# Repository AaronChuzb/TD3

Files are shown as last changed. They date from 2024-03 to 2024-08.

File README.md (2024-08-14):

# TD3-TouchDisplay3.0

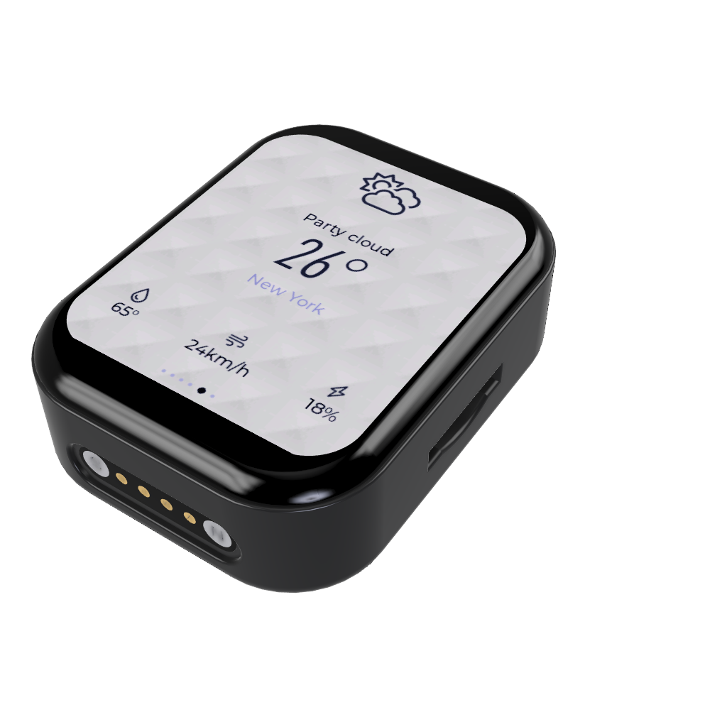
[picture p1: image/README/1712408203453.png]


# 介绍视频



[B站早期视频](https://player.bilibili.com/player.html?isOutside=true&aid=1853047000&bvid=BV1cp421R78N&cid=1508688648&p=1)

# 复刻注意事项

- 板子厚度选择1.2mm
- 阻抗匹配无要求
- 晶振要买无源的啊（血的教训）

## 锂电池

锂电池使用 `402530`的大小，容量 `300mAh`，目前同体积没找到更好的替代品，体积超过这个规格不适用我的外壳可能放不进去。

购买链接：[【淘宝】限时满20减2 https://m.tb.cn/h.gPwur8v7pjAurAq?tk=iaC63e7ytO5 MF6563 「3.7V聚合物锂电池对讲机故事机行车记录仪音箱通用大容量内置电池」](https://m.tb.cn/h.gPwur8v7pjAurAq?tk=iaC63e7ytO5)

记得叫商家加 `SH1.0`的头子,加头子是免费的，接口方向参考下图，方向跟板子上的母座方向是适配的，当然可以选择不接，同时也不焊接板子上的母座，直接飞线到板子上，但是SH1.0的座子引脚间距还是比较小的。

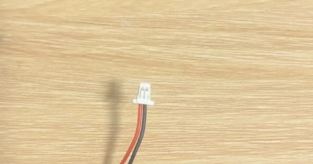
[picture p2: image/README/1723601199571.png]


## 磁吸接口

磁吸接口购买链接尽量使用bom表中的购买地址，3d模型我已经建好了，接口线序我也测过了，直接在那家店买线就ok，未来可能会画一个底座兼容TYPE-C插头。

购买链接：[【淘宝】https://m.tb.cn/h.glr8JNFoAGLjC2Y?tk=W5ul3eFrBDn CZ3460 「pogo pin磁吸式连接器公母带螺丝孔安装 弹簧顶针USB充电导电PIN」
点击链接直接打开 或者 淘宝搜索直接打开](https://m.tb.cn/h.glr8JNFoAGLjC2Y?tk=W5ul3eFrBDn)

购买下面 `4pin`的线，座子 `选弯头3.0mm的但是实际不是要3mm的`，要找客服说要2.54mm的 他们没挂链接，所以只能这样拍,记得一定要联系客服联系客服！！

## 无线充电

目前这块芯片在淘宝上好像只有一家代理商，并且配套的线圈在他们那里也能买到，这块芯片的外围阻容对材质是有要求的，`请先看数据手册的典型电路，再去购买对应的阻容，这一点在bom表中并没有体现出来`。数据手册那些问商家要就好了，项目的docs文件夹里边也有。

购买链接：[【淘宝】https://m.tb.cn/h.glhmi1BjbDgyDQN?tk=bRlC3eFFOLT MF7997 「原装现货代理伏达无线充电接收芯片NU1680/NU1680C，符合Qi标准」
点击链接直接打开 或者 淘宝搜索直接打开](https://m.tb.cn/h.glhmi1BjbDgyDQN?tk=bRlC3eFFOLT)

线圈选他们店里的NU1680配套线圈记得选 `方的`那块

## 屏幕BTB座

型号：`OK-14GF024-04`母座

这座子超过5毛就不要买了，有点难焊，建议淘宝打个钢网配合铁板烧或者风枪吹脚，尽量多买一点。

## 2.4G陶瓷天线

6块钱20片要什么自行车？商家估计还会主动联系帮做匹配电路，其实也不用板子我实测TX可以到18dbm，某C3板子开到15都不行。板子上预留了Π型电路，牛逼的大佬可以自己做天线的阻抗匹配。

购买链接：[【淘宝】https://m.tb.cn/h.glhqlfbUDg5LPQ1?tk=XRp63eFBeyH MF1643 「原装贴片天线3216蓝牙天线CW324WIFI2.4G 2.5G 4G 5G陶瓷1206天线」
点击链接直接打开 或者 淘宝搜索直接打开](https://m.tb.cn/h.glhqlfbUDg5LPQ1?tk=XRp63eFBeyH)

## AXP173电源管理芯片

这片子确实不太好买，定制电压的版本太多，而且停产挺久了，用这个方案主要是我手里还有十几块没用完。
可以在淘宝上购买一两片样片回来测试，`只需要DCDC1输出是3.3V`就OK。

买到合适的可以提一个issure，或者直接提一个pr，更新到这个表当中

| DCDC1输出 | 价格 | 购买链接 |
| --- | ---- | --- |
| | | |
| | | |

## 蜂鸣器

淘宝搜`DET402`,不要问我为啥用这么多非标硬件，主要是以前项目的一些遗留品，结合手里的显示屏，做的项目。

## 模型打印

答应我选尼龙好吗，嘉立创三维猴打一个PA12的才15.5，树脂的会有一个问题热熔螺母嵌套不进去。按钮打一个就行了，一般都会多打几个给你 毕竟这么小。

热熔螺母购买链接： [【淘宝】限时满2减1 https://m.tb.cn/h.glbH1XjvrZgsixS?tk=2SyC3ev3ag4 CZ3460 「注塑热熔铜螺母M2M3通孔滚花螺帽土八字预埋铜嵌件铜花母M4M5M6M8」
点击链接直接打开 或者 淘宝搜索直接打开](https://m.tb.cn/h.glbH1XjvrZgsixS?tk=2SyC3ev3ag4)

热熔螺母规格选`M2x3x3.2`

烙铁开到`250度`就可以顶进去，当然我指的是`PA12`，选其他材质打印的请自行测试。

# TD3 项目配置

1. 基于 `esp-idf5.1.2`版本开发，后续可能会更换威更新的 idf 版本
2. `lvgl`版本为 `8.3.11`，后续可能会升级到 `9`

## 环境配置

拉取下来的代码是不包含 `.vscode`文件夹的，需要打开一个 idf 示例项目,然后复制.`vscode`文件夹到项目根目录下即可

## 目标板配置

1. 设置当前目标板：
   左下角点击随后选择当前的工作区
2. 选择当前第一个如图所示的工作区



3. 选择 `esp32s3`

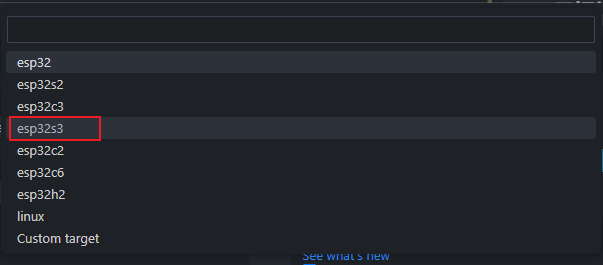
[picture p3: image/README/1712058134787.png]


4. 选择 `via ESP-PROG`项



## menuconfig 内容配置

1. 先点击左下角弹出
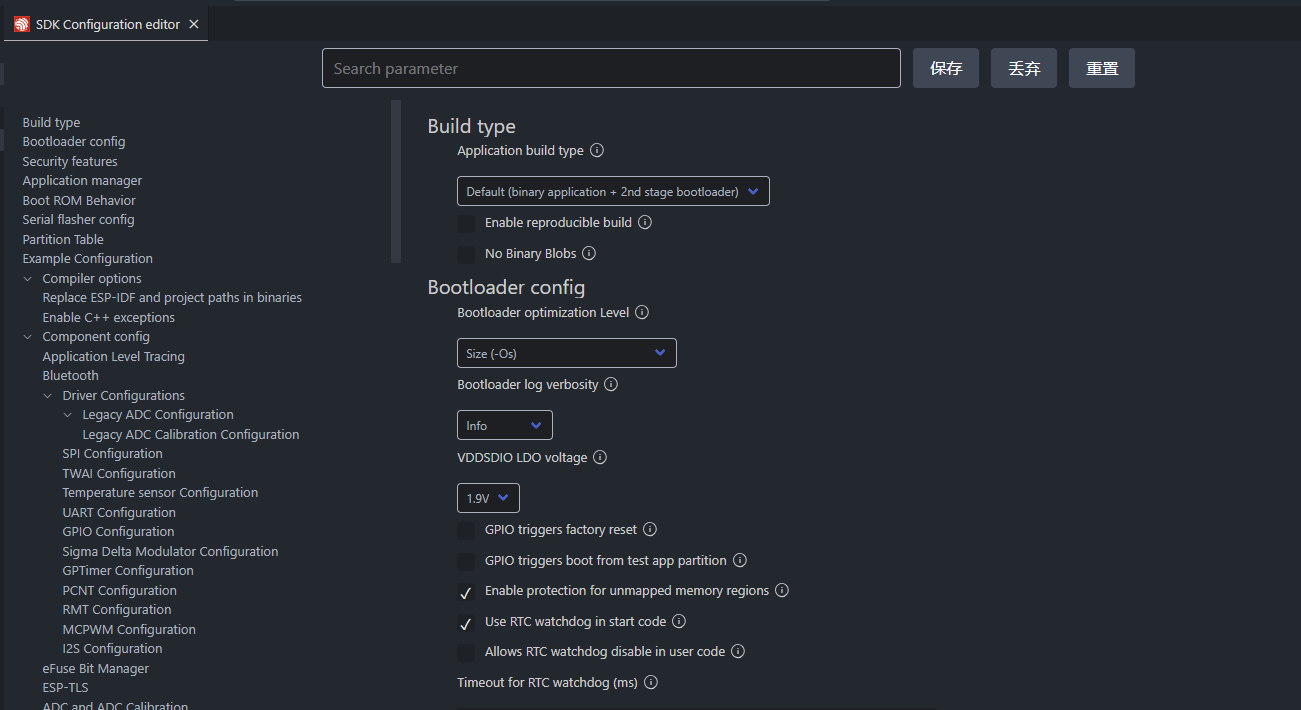
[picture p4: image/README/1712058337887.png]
   
2. 点击保存随后会自动生成 `sdkconfig`文件
3. 将 `sdkconfig.temp`文件内的内容复制并替换 `sdkconfig`文件内的内容

## 项目文件结构说明

```
├─components
│  ├─axp173       // AXP173电源管理驱动
│  ├─backlight    // AW9364驱动
│  ├─beep         // 蜂鸣器驱动
│  ├─bmp280       // BMP280驱动
│  ├─espressif__cmake_utilities
│  ├─espressif__esp_lcd_gc9b71
│  ├─espressif__esp_lcd_touch
│  ├─espressif__esp_lcd_touch_cst816s
│  ├─i2c          // I2C驱动
│  ├─lsm6ds3      // LSM6DS3驱动
│  ├─lvgl         // LVGL
│  ├─pcf8563      // PCF8563驱动
│  └─qmc5883l     // QMC5883L驱动
│
├─docs
│
├─image
├─main
│   │  CMakeLists.txt
│   │  main.c
│   ├─HAL   // 硬件抽象层提供硬件的接口
│   ├─Model // 模型层主要处理数据，创建消息队列，创建采集任务
│   └─View  // mvvm结构中viewmodel层主要放生成的UI
│  .gitignore
│  CMakeLists.txt
│  partitions.csv
│  README.md
│  sdkconfig
│  sdkconfig.old
│  sdkconfig.temp
```

## flash download tools 烧录（不需要bin文件烧录请忽略）

1. 单独的 bin 文件烧录方式| bin                  | 地址    |
   | -------------------- | ------- |
   | bootloader.bin       | 0x0     |
   | partition-table      | 0x8000  |
   | ota_data_initial.bin | 0xd000  |
   | TD3V2.0.bin          | 0x10000 |
2. 合并的 bin 文件烧录方式| bin        | 地址 |
   | ---------- | ---- |
   | target.bin | 0x0  |
3. SPIFlashConfiig| 配置项    | 选项  |
   | --------- | ----- |
   | SPI SPEED | 80MHz |
   | SPI MODE  | DOUT  |
4. 烧录后手动关机重启即可

# 页面管理框架的介绍

这个页面管理框架是我从老的 TD3-App 项目移植过来的，原项目基于 Arduino 平台开发，所以使用的是 c++，但是 idf 是 c 的，虽然 idf 支持 c++混编但是太麻烦所以改成 c，失去了类跟命名空间。

## 如何添加页面

1. 在 `main\View\Pages`目录下新建你的页面文件夹，文件夹包含 xxx.c 文件和 xxx.h 文件，xxx 为你的页面名。

其中.c 文件需要遵循标准模板如下：

```
#include "Setting.h"

PageType *Setting;

static void Created()
{

}

static void Update(void)
{
}

static void Destroy(void)
{
  if (lv_obj_is_valid(Setting->PageContent))
  {
    lv_async_call(lv_obj_clean, Setting->PageContent);
  }
}

static void Method(void *btn, int event)
{
}

void Setting_Init()
{
  Setting = lv_mem_alloc(sizeof(PageType));
  strcpy(Setting->name, "Setting");
  Setting->show_status_bar = 1;
  Setting->BeforeEnter = NULL;
  Setting->Created = Created;
  Setting->Update = Update;
  Setting->Destroy = Destroy;
  Setting->Method = Method;
  Setting->PageContent = create_new_screen();
  Page_Register(*Setting);
}
```

只需要将文件中的全部 `Home`替换成其他名字即可。

.h 文件就比较简单,同样是将 Home 全部换成自己的，然后条件编译那里的大写 HOME 也改掉就行。

```
#ifndef SETTING_H
#define SETTING_H

#ifdef __cplusplus
extern "C" {
#endif

#include "Page.h"

void Setting_Init();

#ifdef __cplusplus
} /*extern "C"*/
#endif

#endif
```

## 优设标题黑取模文字内容

```
电池信息陀螺仪气压计储存卡实时时钟系统设置网络信息天气查询音乐蓝牙蜂鸣器配置串口数据上位机监控连接断开终端
```

2. 修改 `main\CMakeLists.txt`添加 `"View/Pages/xxx"`其中 xxx 为你的页面目录名，至于为什么不写一个统一的 cmake 文件需要时遵循 idf 的项目标准，其实时不会，对就是“不会”。

# 项目开发过程的问题记录（复刻无需关注）

## lvgl 使用 fatfs

1. menuconfig 勾选

`3rd Party Libraries`目录下 `File system on top of FatFS`，同时 `Set an upper cased letter on which the drive will accessible (e.g. 'A' i.e. 65) `改成 `48`，`>0 to cache this number of bytes in lv_fs_read()`改成 `10240`也就是 10k

2. cmake 修改

`components\lvgl\env_support\cmake\esp.cmake`这个文件内需要在 `idf_component_register`的 `REQUIRES`内添加 `fatfs`才不会报 `ff.h`文件找不到的问题

3. 解决 ` unknown type name 'DIR';`问题

`components\lvgl\src\extra\libs\fsdrv\lv_fs_fatfs.c`文件添加头文件 `#include <dirent.h>`

## FreeRTOS 如何使用外部内存的问题

参考[官方文档](https://docs.espressif.com/projects/esp-idf/zh_CN/latest/esp32/migration-guides/release-5.x/5.1/system.html)的说明，由于允许将 FreeRTOS 对象（如队列和信号量）放置在外部 RAM 中可能会出现问题，例如如果在访问这些对象时 cache 被禁用（如在 SPI flash 写入操作期间），则会导致 cache 访问错误（详细信息请参阅 严重错误）。

但是需要使用外部内存堆栈的原因是给 lvgl 创建刷新任务，是任务所以不会存在产生严重错误的问题。

根据附加 API 的说法添加 freertos/esp_additions/include/freertos/idf_additions.h 头文件，包含了 ESP-IDF 添加的与 FreeRTOS 相关的辅助函数。通过 #include "freertos/idf_additions.h" 可添加此头文件。然后就可以使用 xTaskCreateWithCaps 创建任务。相比于动态创建任务只需要在最后添加一个申请内存方式即可

## 移植 rlottie 问题

1. 将 `rlottie`文件夹放入 lvgl 根目录
2. 编辑 `components\lvgl\env_support\cmake`目录下的 `esp.cmake`文件，在文件最上方添加

```
# rlottie
# add_subdirectory(rlottie)
# include_directories(${LVGL_ROOT_DIR}/rlottie/inc)
if (NOT CMAKE_BUILD_TYPE)
    set(CMAKE_BUILD_TYPE MinSizeRel)
endif()

set(BUILD_SHARED_LIBS OFF)

option(LOTTIE_MODULE "Enable LOTTIE MODULE SUPPORT" OFF)
option(LOTTIE_THREAD "Enable LOTTIE THREAD SUPPORT" OFF)
option(LOTTIE_CACHE "Enable LOTTIE CACHE SUPPORT" ON)
option(LOTTIE_TEST "Build LOTTIE AUTOTESTS" OFF)
option(LOTTIE_CCACHE "Enable LOTTIE ccache SUPPORT" OFF)
option(LOTTIE_ASAN "Compile with asan" OFF)

file(GLOB_RECURSE RLOTTIE_SRCS ${LVGL_ROOT_DIR}/rlottie/src/*.cpp)
set(RLOTTIE_INCS
    ${LVGL_ROOT_DIR}/rlottie/inc/
    ${LVGL_ROOT_DIR}/rlottie/src/vector/
)

```

修改 `idf_component_register`行为

```
idf_component_register(SRCS ${SOURCES} ${EXAMPLE_SOURCES} ${DEMO_SOURCES} ${RLOTTIE_SRCS}
      INCLUDE_DIRS ${LVGL_ROOT_DIR} ${LVGL_ROOT_DIR}/src ${LVGL_ROOT_DIR}/../
                   ${LVGL_ROOT_DIR}/examples ${LVGL_ROOT_DIR}/demos ${RLOTTIE_INCS}
      REQUIRES esp_timer fatfs heap)
```

其中 heap 为本次添加

2. 修改 `components\lvgl\rlottie\src\vector\stb\stb_image.h`文件内的内容,注释第 3818 行内容

```
// stbi__errpuc("outofmem", "Out of memory");
```

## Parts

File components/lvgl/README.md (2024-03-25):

<h1 align="center"> LVGL - Light and Versatile Graphics Library</h1>

<p align="center">

</p>

<p align="center">
LVGL provides everything you need to create an embedded GUI with easy-to-use graphical elements, beautiful visual effects and a low memory footprint.
</p>

<h4 align="center">
<a href="https://lvgl.io">Website </a> &middot;
<a href="https://docs.lvgl.io/">Docs</a> &middot;
<a href="https://forum.lvgl.io">Forum</a>  &middot;
<a href="https://lvgl.io/services">Services</a>  &middot;
<a href="https://docs.lvgl.io/master/examples.html">Interactive examples</a>
</h4>

**English** | [中文](./README_zh.md) | [Português do Brasil](./README_pt_BR.md)

---

#### Table of content
- [Overview](#overview)
- [Get started](#get-started)
- [Examples](#examples)
- [Services](#services)
- [Contributing](#contributing)

## Overview
### Features
* Powerful [building blocks](https://docs.lvgl.io/master/widgets/index.html): buttons, charts, lists, sliders, images, etc.
* Advanced graphics engine: animations, anti-aliasing, opacity, smooth scrolling, blending modes, etc
* Supports [various input devices](https://docs.lvgl.io/master/overview/indev.html): touchscreen, mouse, keyboard, encoder, buttons, etc.
* Supports [multiple displays](https://docs.lvgl.io/master/overview/display.html)
* Hardware independent, can be use with any microcontroller and display
* Scalable to operate with little memory (64 kB Flash, 16 kB RAM)
* Multi-language support with UTF-8 handling, CJK, Bidirectional and Arabic script support
* Fully customizable graphical elements via [CSS-like styles](https://docs.lvgl.io/master/overview/style.html)
* Powerful layouts inspired by CSS: [Flexbox](https://docs.lvgl.io/master/layouts/flex.html) and [Grid](https://docs.lvgl.io/master/layouts/grid.html)
* OS, External memory and GPU are supported but not required. (built in support for STM32 DMA2D, SWM341 DMA2D, and NXP PXP and VGLite)
* Smooth rendering even with a [single frame buffer](https://docs.lvgl.io/master/porting/display.html)
* Written in C and compatible with C++
* Micropython Binding exposes [LVGL API in Micropython](https://blog.lvgl.io/2019-02-20/micropython-bindings)
* [Simulator](https://docs.lvgl.io/master/get-started/platforms/pc-simulator.html) to develop on PC without embedded hardware
* 100+ simple [Examples](https://github.com/lvgl/lvgl/tree/master/examples)
* [Documentation](http://docs.lvgl.io/) and API references online and in PDF

### Requirements
Basically, every modern controller (which is able to drive a display) is suitable to run LVGL. The minimal requirements are:
<table>
  <tr>
    <td> <strong>Name</strong> </td>
    <td><strong>Minimal</strong></td>
    <td><strong>Recommended</strong></td>
  </tr>
  <tr>
    <td><strong>Architecture</strong></td>
    <td colspan="2">16, 32 or 64 bit microcontroller or processor</td>
  </tr>
  <tr>
    <td> <strong>Clock</strong></td>
    <td> &gt; 16 MHz </td>
    <td> &gt; 48 MHz</td>
  </tr>

  <tr>
    <td> <strong>Flash/ROM</strong></td>
    <td> &gt; 64 kB </td>
    <td> &gt; 180 kB</td>
  </tr>

  <tr>
    <td> <strong>Static RAM</strong></td>
    <td> &gt; 16 kB </td>
    <td> &gt; 48 kB</td>
  </tr>

  <tr>
    <td> <strong>Draw buffer</strong></td>
    <td> &gt; 1 &times; <em>hor. res.</em> pixels </td>
    <td> &gt; 1/10 screen size </td>
  </tr>

  <tr>
    <td> <strong>Compiler</strong></td>
    <td colspan="2"> C99 or newer </td>
  </tr>
</table>

*Note that the memory usage might vary depending on the architecture, compiler and build options.*

### Supported platforms
LVGL is completely platform independent and can be used with any MCU that fulfills the requirements.
Just to mention some platforms:
- NXP: Kinetis, LPC, iMX, iMX RT
- STM32F1, STM32F3, STM32F4, STM32F7, STM32L4, STM32L5, STM32H7
- Microchip dsPIC33, PIC24, PIC32MX, PIC32MZ
- [Linux frame buffer](https://blog.lvgl.io/2018-01-03/linux_fb) (/dev/fb)
- [Raspberry Pi](https://github.com/lvgl/lv_port_linux_frame_buffer)
- [Espressif ESP32](https://github.com/lvgl/lv_port_esp32)
- [Infineon Aurix](https://github.com/lvgl/lv_port_aurix)
- Nordic NRF52 Bluetooth modules
- Quectel modems
- [SYNWIT SWM341](http://www.synwit.cn/)

LVGL is also available as:
- [Arduino library](https://docs.lvgl.io/master/get-started/platforms/arduino.html)
- [PlatformIO package](https://registry.platformio.org/libraries/lvgl/lvgl)
- [Zephyr library](https://docs.zephyrproject.org/latest/reference/kconfig/CONFIG_LVGL.html)
- [ESP32 component](https://docs.lvgl.io/master/get-started/platforms/espressif.html)
- [NXP MCUXpresso component](https://www.nxp.com/design/software/embedded-software/lvgl-open-source-graphics-library:LITTLEVGL-OPEN-SOURCE-GRAPHICS-LIBRARY)
- [NuttX library](https://docs.lvgl.io/master/get-started/os/nuttx.html)
- [RT-Thread RTOS](https://docs.lvgl.io/master/get-started/os/rt-thread.html)

## Get started
This list shows the recommended way of learning the library:
1. Check the [Online demos](https://lvgl.io/demos) to see LVGL in action (3 minutes)
2. Read the [Introduction](https://docs.lvgl.io/master/intro/index.html) page of the documentation (5 minutes)
3. Get familiar with the basics on the [Quick overview](https://docs.lvgl.io/master/get-started/quick-overview.html) page (15 minutes)
4. Set up a [Simulator](https://docs.lvgl.io/master/get-started/platforms/pc-simulator.html) (10 minutes)
5. Try out some [Examples](https://github.com/lvgl/lvgl/tree/master/examples)
6. Port LVGL to a board. See the [Porting](https://docs.lvgl.io/master/porting/index.html) guide or check the ready to use [Projects](https://github.com/lvgl?q=lv_port_)
7. Read the [Overview](https://docs.lvgl.io/master/overview/index.html) page to get a better understanding of the library (2-3 hours)
8. Check the documentation of the [Widgets](https://docs.lvgl.io/master/widgets/index.html) to see their features and usage
9. If you have questions go to the [Forum](http://forum.lvgl.io/)
10. Read the [Contributing](https://docs.lvgl.io/master/CONTRIBUTING.html) guide to see how you can help to improve LVGL (15 minutes)

## Examples

For more examples see the [examples](https://github.com/lvgl/lvgl/tree/master/examples) folder.

LVGL button with label example

### C
```c
lv_obj_t * btn = lv_btn_create(lv_scr_act());                   /*Add a button to the current screen*/
lv_obj_set_pos(btn, 10, 10);                                    /*Set its position*/
lv_obj_set_size(btn, 100, 50);                                  /*Set its size*/
lv_obj_add_event_cb(btn, btn_event_cb, LV_EVENT_CLICKED, NULL); /*Assign a callback to the button*/

lv_obj_t * label = lv_label_create(btn);                        /*Add a label to the button*/
lv_label_set_text(label, "Button");                             /*Set the labels text*/
lv_obj_center(label);                                           /*Align the label to the center*/
...

void btn_event_cb(lv_event_t * e)
{
  printf("Clicked\n");
}
```
### Micropython
Learn more about [Micropython](https://docs.lvgl.io/master/get-started/bindings/micropython.html).
```python
def btn_event_cb(e):
  print("Clicked")

# Create a Button and a Label
btn = lv.btn(lv.scr_act())
btn.set_pos(10, 10)
btn.set_size(100, 50)
btn.add_event_cb(btn_event_cb, lv.EVENT.CLICKED, None)

label = lv.label(btn)
label.set_text("Button")
label.center()
```

## Services
LVGL Kft was established to provide a solid background for LVGL library. We offer several type of services to help you in UI development:
- Graphics design
- UI implementation
- Consulting/Support

For more information see https://lvgl.io/services
Feel free to contact us if you have any questions.

## Contributing
LVGL is an open project and contribution is very welcome. There are many ways to contribute from simply speaking about your project, through writing examples, improving the documentation, fixing bugs to hosting your own project under the LVGL organization.

For a detailed description of contribution opportunities visit the [Contributing](https://docs.lvgl.io/master/CONTRIBUTING.html) section of the documentation.

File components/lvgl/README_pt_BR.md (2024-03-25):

<h1 align="center"> LVGL - Biblioteca gráfica leve e versátil</h1>
<p align="center">
    
</p>
<p align="center">
    O LVGL fornece tudo o que você precisa para criar uma GUI incorporada com elementos gráficos fáceis de usar, belos efeitos visuais e um baixo consumo de memória.
</p>
<h4 align="center">
    <a href="https://lvgl.io">Site</a> &middot;
    <a href="https://docs.lvgl.io/">Documentação</a> &middot;
    <a href="https://forum.lvgl.io">Fórum</a> &middot;
    <a href="https://lvgl.io/services">Serviços</a> &middot;
    <a href="https://docs.lvgl.io/master/examples.html">Exemplos interativos</a>
</h4>

[English](./README.md) | [中文](./README_zh.md) | **Português do Brasil**

---

### Tabela de conteúdo

- [Visão Geral](#visão-geral)
- [Iniciando](#iniciando)
- [Exemplos](#exemplos)
- [Serviços](#serviços)
- [Contribuindo](#contribuindo)

## Visão Geral

### Recursos
* Poderosos [widgets](https://docs.lvgl.io/master/widgets/index.html): botões, gráficos, listas, controles deslizantes (sliders), imagens, etc.
* Mecanismo gráfico avançado: animações, anti-aliasing, opacidade, rolagem suave, modos de mesclagem (blending modes), etc.
* Suporte à [vários dispositivos de entrada](https://docs.lvgl.io/master/overview/indev.html): tela sensível ao toque, mouse, teclado, codificador, botões, etc.
* Suporte à [vários monitores](https://docs.lvgl.io/master/overview/display.html)
* Pode ser usado com qualquer microcontrolador e display, independente do hardware
* Escalável para operar com pouca memória (64 kB Flash, 16 kB RAM)
* Suporte multilíngue com manipulação UTF-8, suporte ao alfabeto bidirecional, árabe e CJK (Chinês, Japonês e Coreano)
* Elementos gráficos totalmente personalizáveis por meio de [CSS](https://docs.lvgl.io/master/overview/style.html)
* Layouts poderosos inspirados em CSS: [Flexbox](https://docs.lvgl.io/master/layouts/flex.html) e [Grid](https://docs.lvgl.io/master/layouts/grid.html)
* SO, memória externa e GPU são suportados, mas não obrigatórios. (suporte integrado para STM32 DMA2D, SWM341 DMA2D e NXP PXP e VGLite)
* Renderização suave mesmo com um [buffer de quadro único](https://docs.lvgl.io/master/porting/display.html) (single frame buffer)
* Escrito em C e compatível com C++
* Uso do LittlevGL com Micropython simplificado com [LVGL API in Micropython](https://blog.lvgl.io/2019-02-20/micropython-bindings)
* [Simulador](https://docs.lvgl.io/master/get-started/platforms/pc-simulator.html) para desenvolver no PC sem hardware embutido
* Mais de 100 [exemplos simples](https://github.com/lvgl/lvgl/tree/master/examples)
* [Documentação](http://docs.lvgl.io/) e referências de API online e em PDF

### Requerimentos
Basicamente, todo controlador moderno (que é capaz de acionar um display) é adequado para executar LVGL. Os requisitos mínimos são:

<table>
  <tr>
    <td>
        <strong>Nome</strong>
    </td>
    <td>
        <strong>Minímo</strong>
    </td>
    <td>
        <strong>Recomendado</strong>
    </td>
  </tr>
  <tr>
    <td>
        <strong>Arquitetura</strong>
    </td>
    <td colspan="2">Microcontrolador ou processador de 16, 32 ou 64 bits</td>
  </tr>
  <tr>
    <td>
        <strong>Clock</strong>
    </td>
    <td>&gt; 16 MHz</td>
    <td>&gt; 48 MHz</td>
  </tr>
  <tr>
    <td>
        <strong>Flash/ROM</strong>
    </td>
    <td>&gt; 64 kB</td>
    <td>&gt; 180 kB</td>
  </tr>

  <tr>
    <td>
        <strong>RAM estática</strong>
    </td>
    <td>&gt; 16 kB</td>
    <td>&gt; 48 kB</td>
  </tr>

  <tr>
    <td>
        <strong>Draw buffer</strong>
    </td>
    <td>&gt; 1 &times; <em>hor. res.</em> pixels</td>
    <td>&gt; tamanho da tela de 1/10</td>
  </tr>

  <tr>
    <td>
        <strong>Compilador</strong>
    </td>
    <td colspan="2">Padrão C99 ou mais recente</td>
  </tr>
</table>

*Observe que o uso de memória pode variar dependendo da arquitetura, do compilador e das opções de compilação.*

### Plataformas suportadas
O LVGL é completamente independente de plataforma e pode ser usado com qualquer MCU que atenda aos requisitos.
Apenas para citar algumas plataformas:

- NXP: Kinetis, LPC, iMX, iMX RT
- STM32F1, STM32F3, STM32F4, STM32F7, STM32L4, STM32L5, STM32H7
- Microchip dsPIC33, PIC24, PIC32MX, PIC32MZ
- [Linux frame buffer](https://blog.lvgl.io/2018-01-03/linux_fb) (/dev/fb)
- [Raspberry Pi](http://www.vk3erw.com/index.php/16-software/63-raspberry-pi-official-7-touchscreen-and-littlevgl)
- [Espressif ESP32](https://github.com/lvgl/lv_port_esp32)
- [Infineon Aurix](https://github.com/lvgl/lv_port_aurix)
- Nordic NRF52 Bluetooth modules
- Quectel modems
- [SYNWIT SWM341](https://www.synwit.cn/)

LVGL também está disponível para:
- [Arduino library](https://docs.lvgl.io/master/get-started/platforms/arduino.html)
- [PlatformIO package](https://registry.platformio.org/libraries/lvgl/lvgl)
- [Zephyr library](https://docs.zephyrproject.org/latest/reference/kconfig/CONFIG_LVGL.html)
- [ESP32 component](https://docs.lvgl.io/master/get-started/platforms/espressif.html)
- [NXP MCUXpresso component](https://www.nxp.com/design/software/embedded-software/lvgl-open-source-graphics-library:LITTLEVGL-OPEN-SOURCE-GRAPHICS-LIBRARY)
- [NuttX library](https://docs.lvgl.io/master/get-started/os/nuttx.html)
- [RT-Thread RTOS](https://docs.lvgl.io/master/get-started/os/rt-thread.html)

## Iniciando
Esta lista mostra a maneira recomendada de aprender sobre a biblioteca:

1. Confira as [demos on-line](https://lvgl.io/demos) para ver o LVGL em ação (3 minutos)
2. Leia a [introdução](https://docs.lvgl.io/master/intro/index.html) da documentação (5 minutos)
3. Familiarize-se com o básico da [Visão geral rápida](https://docs.lvgl.io/master/get-started/quick-overview.html) (15 minutos)
4. Configure um [simulador](https://docs.lvgl.io/master/get-started/platforms/pc-simulator.html) (10 minutos)
5. Experimente alguns [Exemplos](https://github.com/lvgl/lvgl/tree/master/examples)
6. Placa para porta LVGL. Veja o guia [porting](https://docs.lvgl.io/master/porting/index.html) ou verifique o pronto para usar [Projects](https://github.com/lvgl?q=lv_port_)
7. Leia a [visão geral](https://docs.lvgl.io/master/overview/index.html) para entender melhor a biblioteca (2-3 horas)
8. Verifique a documentação dos [widgets](https://docs.lvgl.io/master/widgets/index.html) para ver seus recursos e como utilizá-los
9. Se você tiver dúvidas, acesse o [fórum](http://forum.lvgl.io/)
10. Leia o guia de [contribuição](https://docs.lvgl.io/master/CONTRIBUTING.html) para ver como você pode ajudar a melhorar o LVGL (15 minutos)

## Exemplos
Para mais exemplos, veja a pasta [examples](https://github.com/lvgl/lvgl/tree/master/examples).

Exemplo de botão LVGL com rótulo (label)

### C

```c
lv_obj_t * button = lv_btn_create(lv_scr_act());                             /* Adiciona um botão à tela atual */
lv_obj_set_pos(button, 10, 10);                                              /* Define uma posição ao botão na tela */
lv_obj_set_size(button, 100, 50);                                            /* Define o tamanho */
lv_obj_add_event_cb(button, button_event_callback, LV_EVENT_CLICKED, NULL);  /* Atribui um retorno de chamada (callback) */

lv_obj_t * label = lv_label_create(button);                                  /* Adiciona um rótulo (label) */
lv_label_set_text(label, "Clique aqui");                                     /* Define o texto do rótulo (label) */
lv_obj_center(label);                                                        /* Alinha o texto ao centro */
...

void button_event_callback(lv_event_t * e)
{
  printf("Clicado\n");
}
```

### Micropython
Saiba mais em [Micropython](https://docs.lvgl.io/master/get-started/bindings/micropython.html)

```python
def button_event_callback(event):
  print("Clicado")

# Cria um botão e um rótulo (label)
button = lv.btn(lv.scr_act())
button.set_pos(10, 10)
button.set_size(100, 50)
button.add_event_cb(button_event_callback, lv.EVENT.CLICKED, None)

label = lv.label(button)
label.set_text("Cliquq aqui")
label.center()
```

## Serviços
O LVGL Kft foi estabelecido para fornecer uma base sólida para a biblioteca LVGL. Oferecemos vários tipos de serviços
para ajudá-lo no desenvolvimento da interface do usuário:

- Design gráfico
- Implementação de IU
- Consultoria/Suporte

Para mais informações, consulte [LVGL Serviços](https://lvgl.io/services). Sinta-se à vontade para entrar em contato
conosco se tiver alguma dúvida.

## Contribuindo
O LVGL é um projeto aberto e sua contribuição é muito bem-vinda. Há muitas maneiras de contribuir, desde simplesmente
falando sobre seu projeto, escrevendo exemplos, melhorando a documentação, corrigindo bugs até hospedar seu próprio
projeto sob a organização LVGL.

Para obter uma descrição detalhada das oportunidades de contribuição, visite a seção de [contribuição](https://docs.lvgl.io/master/CONTRIBUTING.html) da documentação.

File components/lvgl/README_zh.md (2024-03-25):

<h1 align="center"> LVGL - Light and Versatile Graphics Library</h1>
<h2 align="center"> LVGL - 轻量级通用型图形库</h2>

<p align="center">

</p>
<p align="center">
LVGL是一个高度可裁剪、低资源占用、界面美观且易用的嵌入式系统图形库
</p>

<h4 align="center">
<a href="https://lvgl.io">官网</a> &middot;
<a href="https://docs.lvgl.io/">文档</a> &middot;
<a href="https://forum.lvgl.io">论坛</a>  &middot;
<a href="https://lvgl.io/services">服务</a>  &middot;
<a href="https://docs.lvgl.io/master/examples.html">例程</a>
</h4>

[English](./README.md) | **中文** | [Português do Brasil](./README_pt_BR.md)

---

#### 目录
- [概况与总览](#概况与总览)
- [如何入门](#如何入门)
- [例程](#例程)
- [服务](#服务)
- [如何向社区贡献](#如何向社区贡献)

## 概况与总览
### 特性
* 丰富且强大的模块化[图形组件](https://docs.lvgl.io/master/widgets/index.html)：按钮 (buttons)、图表 (charts)、列表 (lists)、滑动条 (sliders)、图片 (images) 等
* 高级的图形引擎：动画、抗锯齿、透明度、平滑滚动、图层混合等效果
* 支持多种[输入设备](https://docs.lvgl.io/master/overview/indev.html)：触摸屏、 键盘、编码器、按键等
* 支持[多显示设备](https://docs.lvgl.io/master/overview/display.html)
* 不依赖特定的硬件平台，可以在任何显示屏上运行
* 配置可裁剪（最低资源占用：64 kB Flash，16 kB RAM）
* 基于UTF-8的多语种支持，例如中文、日文、韩文、阿拉伯文等
* 可以通过[类CSS](https://docs.lvgl.io/master/overview/style.html)的方式来设计、布局图形界面（例如：[Flexbox](https://docs.lvgl.io/master/layouts/flex.html)、[Grid](https://docs.lvgl.io/master/layouts/grid.html)）
* 支持操作系统、外置内存、以及硬件加速（LVGL已内建支持STM32 DMA2D、SWM341 DMA2D、NXP PXP和VGLite）
* 即便仅有[单缓冲区(frame buffer)](https://docs.lvgl.io/master/porting/display.html)的情况下，也可保证渲染如丝般顺滑
* 全部由C编写完成，并支持C++调用
* 支持Micropython编程，参见：[LVGL API in Micropython](https://blog.lvgl.io/2019-02-20/micropython-bindings)
* 支持[模拟器](https://docs.lvgl.io/master/get-started/platforms/pc-simulator.html)仿真，可以无硬件依托进行开发
* 丰富详实的[例程](https://github.com/lvgl/lvgl/tree/master/examples)
* 详尽的[文档](http://docs.lvgl.io/)以及API参考手册，可线上查阅或可下载为PDF格式

### 硬件要求

<table>
  <tr>
    <td> <strong>要求</strong> </td>
    <td><strong>最低要求</strong></td>
    <td><strong>建议要求</strong></td>
  </tr>
  <tr>
    <td><strong>架构</strong></td>
    <td colspan="2">16、32、64位微控制器或微处理器</td>
  </tr>
  <tr>
    <td> <strong>时钟</strong></td>
    <td> &gt; 16 MHz</td>
    <td> &gt; 48 MHz</td>
  </tr>

  <tr>
    <td> <strong>Flash/ROM</strong></td>
    <td> &gt; 64 kB </td>
    <td> &gt; 180 kB</td>
  </tr>

  <tr>
    <td> <strong>Static RAM</strong></td>
    <td> &gt; 16 kB </td>
    <td> &gt; 48 kB</td>
  </tr>

  <tr>
    <td> <strong>Draw buffer</strong></td>
    <td> &gt; 1 &times; <em>hor. res.</em> pixels </td>
    <td> &gt; 1/10屏幕大小 </td>
  </tr>

  <tr>
    <td> <strong>编译器</strong></td>
    <td colspan="2"> C99或更新 </td>
  </tr>
</table>

*注意：资源占用情况与具体硬件平台、编译器等因素有关，上表中仅给出参考值*

### 已经支持的平台
LVGL本身并不依赖特定的硬件平台，任何满足LVGL硬件配置要求的微控制器均可运行LVGL。
如下仅列举其中一部分:

- NXP: Kinetis, LPC, iMX, iMX RT
- STM32F1, STM32F3, STM32F4, STM32F7, STM32L4, STM32L5, STM32H7
- Microchip dsPIC33, PIC24, PIC32MX, PIC32MZ
- [Linux frame buffer](https://blog.lvgl.io/2018-01-03/linux_fb) (/dev/fb)
- [Raspberry Pi](http://www.vk3erw.com/index.php/16-software/63-raspberry-pi-official-7-touchscreen-and-littlevgl)
- [Espressif ESP32](https://github.com/lvgl/lv_port_esp32)
- [Infineon Aurix](https://github.com/lvgl/lv_port_aurix)
- Nordic NRF52 Bluetooth modules
- Quectel modems
- [SYNWIT SWM341](https://www.synwit.cn/)

LVGL也支持：
- [Arduino library](https://docs.lvgl.io/master/get-started/platforms/arduino.html)
- [PlatformIO package](https://platformio.org/lib/show/12440/lvgl)
- [Zephyr library](https://docs.zephyrproject.org/latest/reference/kconfig/CONFIG_LVGL.html)
- [ESP32 component](https://docs.lvgl.io/master/get-started/platforms/espressif.html)
- [NXP MCUXpresso component](https://www.nxp.com/design/software/embedded-software/lvgl-open-source-graphics-library:LITTLEVGL-OPEN-SOURCE-GRAPHICS-LIBRARY)
- [NuttX library](https://docs.lvgl.io/master/get-started/os/nuttx.html)
- [RT-Thread RTOS](https://www.rt-thread.org/document/site/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)

## 如何入门
请按照如下顺序来学习LVGL：
1. 使用[网页在线例程](https://lvgl.io/demos)来体验LVGL（3分钟）
2. 阅读文档[简介](https://docs.lvgl.io/master/intro/index.html)章节来初步了解LVGL（5分钟）
3. 再来阅读一下文档快速[快速概览](https://docs.lvgl.io/master/get-started/quick-overview.html)章节来了解LVGL的基本知识（15分钟）
4. 学习如何使用[模拟器](https://docs.lvgl.io/master/get-started/platforms/pc-simulator.html)来在电脑上仿真LVGL（10分钟）
5. 试着动手实践一些[例程](https://github.com/lvgl/lvgl/tree/master/examples)
6. 参考[移植指南](https://docs.lvgl.io/master/porting/index.html)尝试将LVGL移植到一块开发板上，LVGL也已经提供了一些移植好的[工程](https://github.com/lvgl?q=lv_port_)
7. 仔细阅读文档[总览](https://docs.lvgl.io/master/overview/index.html)章节来更加深入的了解和熟悉LVGL（2-3小时）
8. 浏览文档[组件(Widgets)](https://docs.lvgl.io/master/widgets/index.html)章节来了解如何使用它们
9. 如果你有问题可以到LVGL[论坛](http://forum.lvgl.io/)提问
10. 阅读文档[如何向社区贡献](https://docs.lvgl.io/master/CONTRIBUTING.html)章节来看看你能帮LVGL社区做些什么，以促进LVGL软件质量的不断提高（15分钟）

## 例程

更多例程请参见 [examples](https://github.com/lvgl/lvgl/tree/master/examples) 文件夹。

LVGL button with label example

### C
```c
lv_obj_t * btn = lv_btn_create(lv_scr_act());                   /*Add a button to the current screen*/
lv_obj_set_pos(btn, 10, 10);                                    /*Set its position*/
lv_obj_set_size(btn, 100, 50);                                  /*Set its size*/
lv_obj_add_event_cb(btn, btn_event_cb, LV_EVENT_CLICKED, NULL); /*Assign a callback to the button*/

lv_obj_t * label = lv_label_create(btn);                        /*Add a label to the button*/
lv_label_set_text(label, "Button");                             /*Set the labels text*/
lv_obj_center(label);                                           /*Align the label to the center*/
...

void btn_event_cb(lv_event_t * e)
{
  printf("Clicked\n");
}
```
### Micropython
更多信息请到 [Micropython官网](https://docs.lvgl.io/master/get-started/bindings/micropython.html) 查询.
```python
def btn_event_cb(e):
  print("Clicked")

# Create a Button and a Label
btn = lv.btn(lv.scr_act())
btn.set_pos(10, 10)
btn.set_size(100, 50)
btn.add_event_cb(btn_event_cb, lv.EVENT.CLICKED, None)

label = lv.label(btn)
label.set_text("Button")
label.center()
```

## 服务
LVGL 责任有限公司成立的目的是为了给用户使用LVGL图形库提供额外的技术支持，我们致力于提供以下服务：

- 图形设计
- UI设计
- 技术咨询以及技术支持

更多信息请参见 https://lvgl.io/services ，如果有任何问题请随时联系我们。

## 如何向社区贡献
LVGL是一个开源项目，非常欢迎您参与到社区贡献当中。您有很多种方式来为提高LVGL贡献您的一份力量，包括但不限于：

- 介绍你基于LVGL设计的作品或项目
- 写一些例程
- 修改以及完善文档
- 修复bug

请参见文档[如何向社区贡献](https://docs.lvgl.io/master/CONTRIBUTING.html)章节来获取更多信息。

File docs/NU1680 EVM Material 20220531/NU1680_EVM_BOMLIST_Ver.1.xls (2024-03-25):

Bill of Materials |  |  | Bill of Materials For Schematic Document [NU1680_EVM_SCH_Ver.1.SchDoc]
Source Data From: |  | NU1680_EVM_BOMLIST_Ver.1
Project: |  | NU1680 Rx
Variant: |  | None
Creation Date: | 2019/9/19 | 14:21:32
Print Date: | 43766 | 43766.70531
Footprint | Comment | LibRef | Designator | Description | Quantity
SMD_R5_CAP_0402 | 100nF/25V | cap | C2 | 0402 | 1
SMD_R5_CAP_0402 | 82nF/25V | cap | C3 | 0402 | 1
SMD_R5_CAP_0402 | 2.2nF/16V | cap | C4 | 0402 | 1
SMD_R5_CAP_0402 | 47nF/16V | cap | C5, C6 | 0402 | 2
SMD_R5_CAP_0603 | 10uF/16V | cap | C7, C9, C10 | 0603 | 3
SMD_R5_CAP_0402 | 100nF/16V | cap | C8 | 0402 | 1
SMD_R5_CAP_0603 | 4.7uF/10V | cap | C11 | 0603 | 1
SMD_R5_CAP_0402 | 0R | RES | R3 | 0402 | 1
HDR1X2 | 15.8uH | Inductor | L1 | 32mm*20mm | 1
SMD_R5_RES_0805 | 220R | Res1 | R1 | 0805 | 1
NU1680_QFN16 | NU1680 | NU1680 | U1 | QFN 3mm*3mm | 1
 |  |  |  |  | 15
Approved |  | Notes

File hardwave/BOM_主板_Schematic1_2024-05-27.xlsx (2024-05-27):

No. | Quantity | Comment | Designator | Footprint | Value | Supplier
1 | 1 | DET402 | BUZZER1 | BUZ-SMD_L4.0-W3.0-LS4.5-FD |  | 淘宝搜det402，挑便宜的买
2 | 4 | 100nF | C1,C5,C9,C10 | C0402 | 100nF | LCSC
3 | 3 | 1uF | C2,C3,C13 | C0402 | 1uF | LCSC
4 | 1 | 10nF | C4 | C0402 | 10nF | LCSC
5 | 2 | 15pF | C6,C7 | C0402 | 15pF | LCSC
6 | 1 | 10uF | C8 | C0402 | 10uF | LCSC
7 | 5 | 100nF | C21,C33,C40,C49,C50 | C0603 | 100nF | LCSC
8 | 7 | 10uF | C22,C23,C29,C36,C37,C39,C51 | C0603 | 10uF | LCSC
9 | 1 | 1nF | C24 | C0603 | 1nF | LCSC
10 | 1 | 4.7uF | C25 | C0603 | 4.7uF | LCSC
11 | 4 | 1uF | C26,C27,C38,C52 | C0603 | 1uF | LCSC
12 | 1 | 220nF | C28 | C0603 | 220nF | LCSC
13 | 3 | 47nF | C30,C31,C34 | C0603 | 47nF | LCSC
14 | 1 | 2.2nF | C32 | C0603 | 2.2nF | LCSC
15 | 1 | 33nF | C35 | C0603 | 33nF | LCSC
16 | 2 | NC | C53,C54 | C0402 | NC | LCSC
17 | 2 | 18pF | C55,C56 | C0603 | 18pF | LCSC
18 | 1 | A1002WR-S-2P | CN1 | CONN-SMD_A1002WR-S-2P |  | LCSC
19 | 5 | B5819WS | D1,D2,D3,D4,D5 | SOD-323_L1.8-W1.3-LS2.5-RD |  | LCSC
20 | 1 | 2.2uH | L2 | IND-SMD_L2.5-W2.0_SRN2510 | 2.2uH | LCSC
21 | 1 | D-060306R1/SS2/L | LED1 | LED0603-RD |  | LCSC
22 | 1 | BC847BS,115 | Q2 | SOT-363_L2.0-W1.3-P0.65-LS2.1-TL |  | LCSC
23 | 1 | AO3401A | Q3 | SOT-23_L2.9-W1.3-P1.90-LS2.4-BR |  | LCSC
24 | 1 | AO3400A | Q4 | SOT-23-3_L2.9-W1.3-P1.90-LS2.4-BR |  | LCSC
25 | 1 | 10kΩ | R2 | R0402 | 10kΩ | LCSC
26 | 2 | 0Ω | R7,R17 | R0603 | 0Ω | LCSC
27 | 4 | 10kΩ | R8,R18,R19,R21 | R0603 | 10kΩ | LCSC
28 | 1 | 200kΩ | R9 | R0603 | 200kΩ | LCSC
29 | 1 | 100kΩ | R11 | R0603 | 100kΩ | LCSC
30 | 1 | 220Ω | R12 | R0805 | 220Ω | LCSC
31 | 2 | 10kΩ | RN1,RN2 | RES-ARRAY-SMD_0603-8P-L3.2-W1.6-BL | 10kΩ | LCSC
32 | 1 | ST-1186SEM | SW1 | SW-SMD_ST-1186SEM |  | LCSC
33 | 1 | SD | TF1 | TF-SMD_TF-15-15 |  | LCSC
34 | 1 | ESP32-S3(R8) | U1 | QFN-56_L7.0-W7.0-P0.40-TL-EP4.0 |  | LCSC
35 | 1 | W25Q256JVEIQ | U2 | WSON-8_L6.0-W8.0-P1.27-BL-EP |  | LCSC
36 | 1 | BMP280 | U6 | LGA-8_L2.5-W2.0-P0.65_AMP6127 |  | LCSC
37 | 1 | AXP173 | U9 | QFN-32 |  | LCSC | 需要DCDC1输出3.3V的版本
38 | 1 | NU1680 | U10 | QFN-16_L3.0-W3.0-P0.50-TL-EP1.9 |  | https://item.taobao.com/item.htm?_u=r2ce6ade9748&id=743057187945&spm=a1z09.2.0.0.50c52e8dVbk6c2 | 在他们家买配套的线圈，方的那块，他选用的电容有要求，注意看nu1680的文档，结合我给的原理图，他的外围电容材质有要求，BOM表里我没标出来
39 | 1 | 排公排母1*2 | U11 | 排公排母1*2
40 | 1 | 4pin磁吸母座弯头 | U12 | 4pin磁吸母座弯头 |  | https://item.taobao.com/item.htm?_u=r2ce6ade6cfd&id=650683179648&skuId=5021346002202 | 跟店家说要2.54弯头的
41 | 1 | LSM6DS3TR-C | U13 | LGA-14_L3.0-W2.5-P0.50-TL |  | LCSC
42 | 1 | CH340K | U14 | ESOP-10_L4.9-W3.9-P1.00-LS6.2-BL-EP |  | LCSC
43 | 1 | OK-14F024-04 | U15 | CONN-SMD_24P-P0.40_OK-14F024-04-H0189S002T002 V1 |  | LCSC
44 | 1 | AW9364DNR | U16 | DFN-8_L2.0-W2.0-P0.50-BL-EP-1 | - | https://item.taobao.com/item.htm?_u=r2ce6ade0c42&id=749355316056&spm=a1z09.2.0.0.50c52e8dVbk6c2
45 | 1 | ANT3216LL00R2400A | U17 | ANT-SMD_L3.2-W1.6 |  | https://item.taobao.com/item.htm?_u=r2ce6ade21ef&id=724933845035&skuId=5032270040356 | 便宜好用
46 | 1 | PCF8563 | U18 | SOP-8_L4.9-W3.9-P1.27-LS6.0-BL |  | LCSC
47 | 1 | 40MHz | X1 | OSC-SMD_4P-L3.2-W2.5-BL_SIT8008BI | 40MHz | LCSC
48 | 1 | 32.768kHz | X2 | FC-135R_L3.2-W1.5 | 32.768kHz | LCSC
49 | 1 | 1.89寸QSPI屏幕 |  |  |  | https://item.taobao.com/item.htm?id=700030787687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

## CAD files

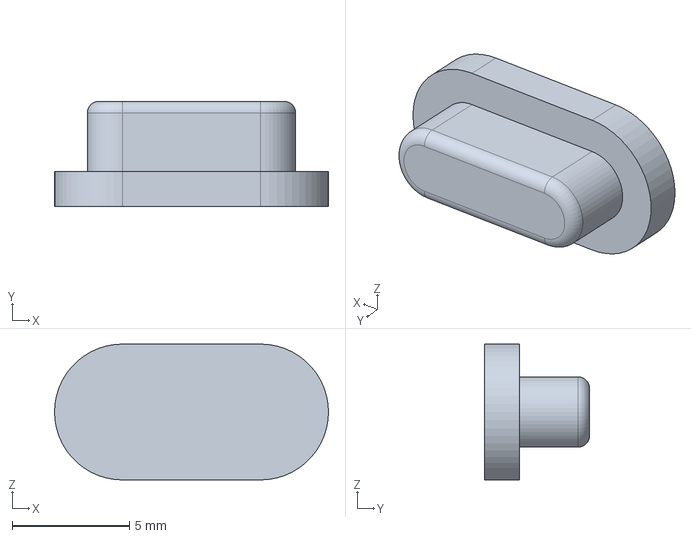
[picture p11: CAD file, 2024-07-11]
hardwave/按钮.step
11.7 x 4.50 x 5.80 mm

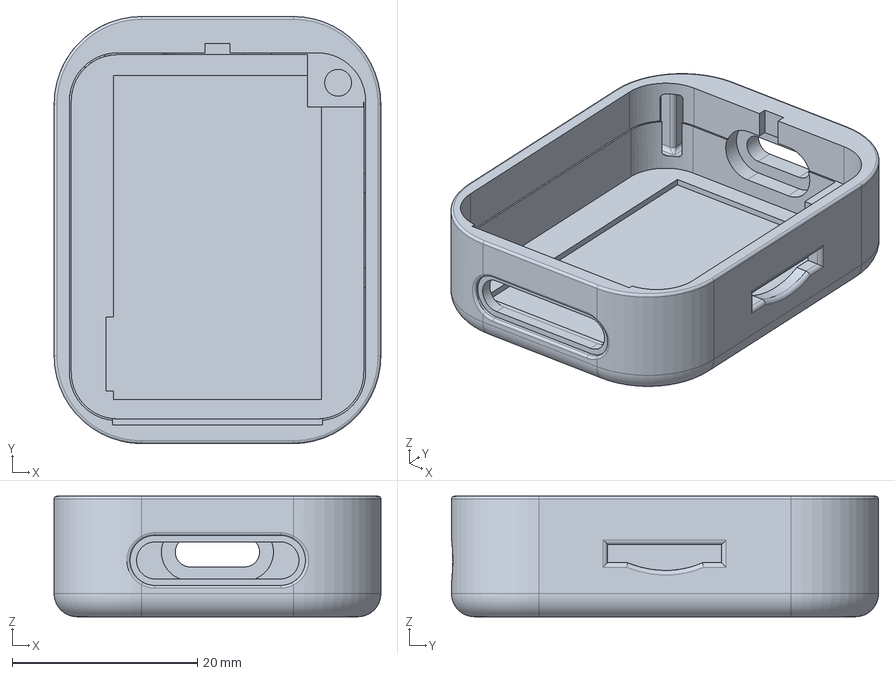
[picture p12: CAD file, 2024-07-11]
hardwave/外壳.step
35.3 x 46.1 x 13.0 mm

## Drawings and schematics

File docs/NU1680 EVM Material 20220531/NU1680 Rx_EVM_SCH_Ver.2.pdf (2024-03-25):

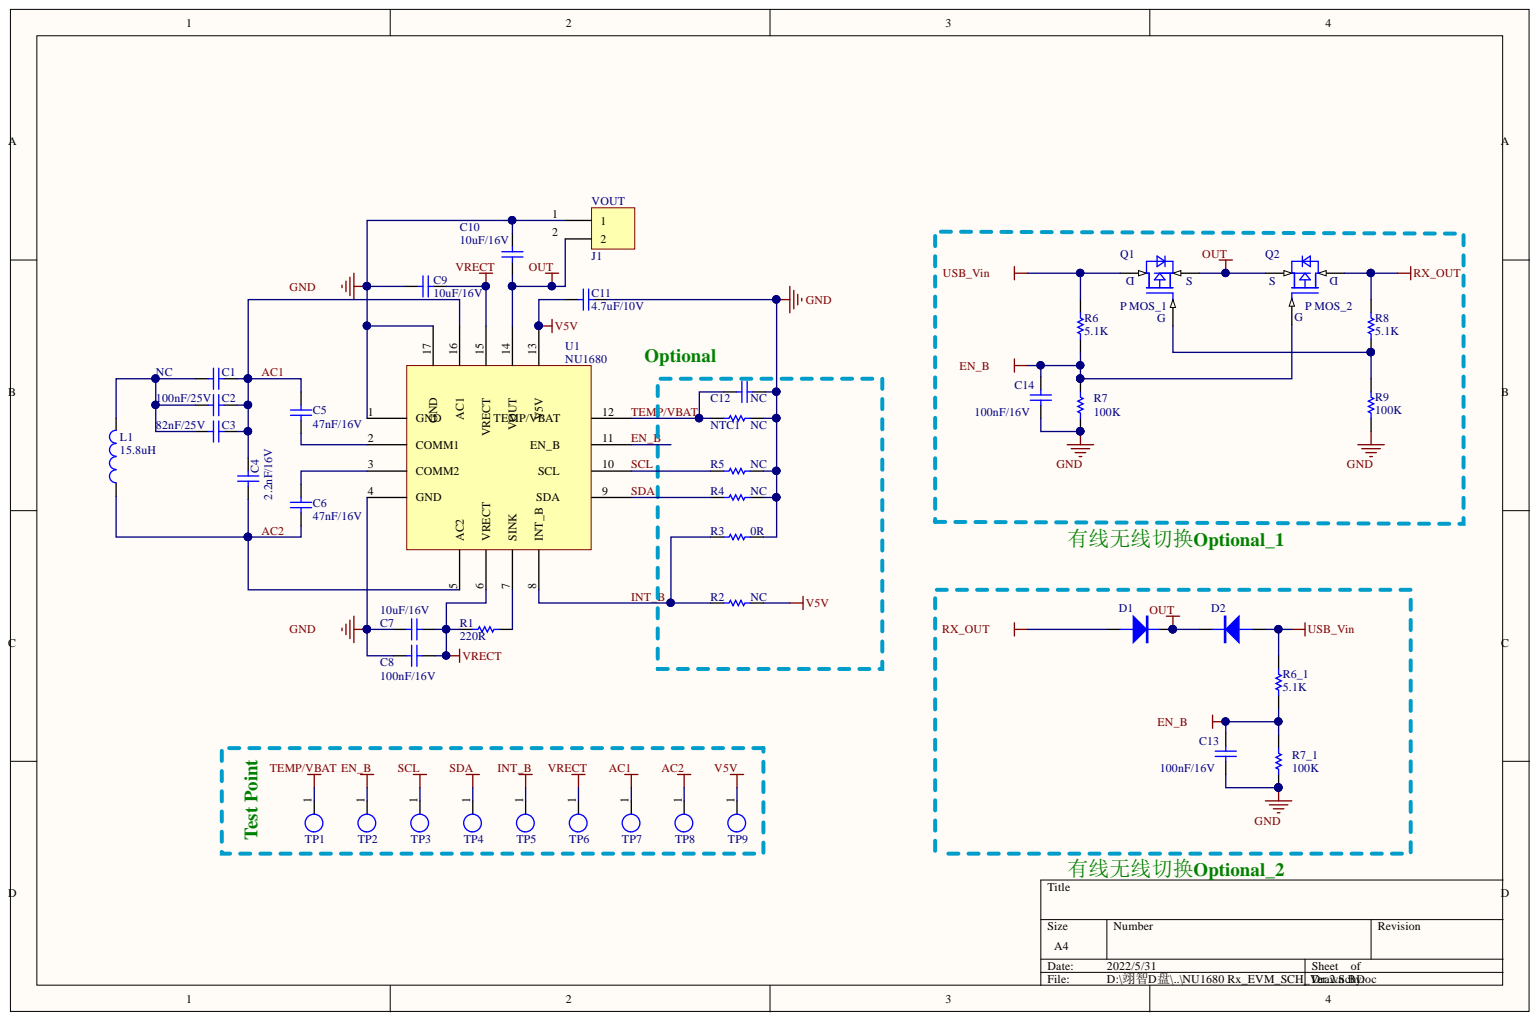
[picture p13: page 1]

C10 10uF/16V VRECT

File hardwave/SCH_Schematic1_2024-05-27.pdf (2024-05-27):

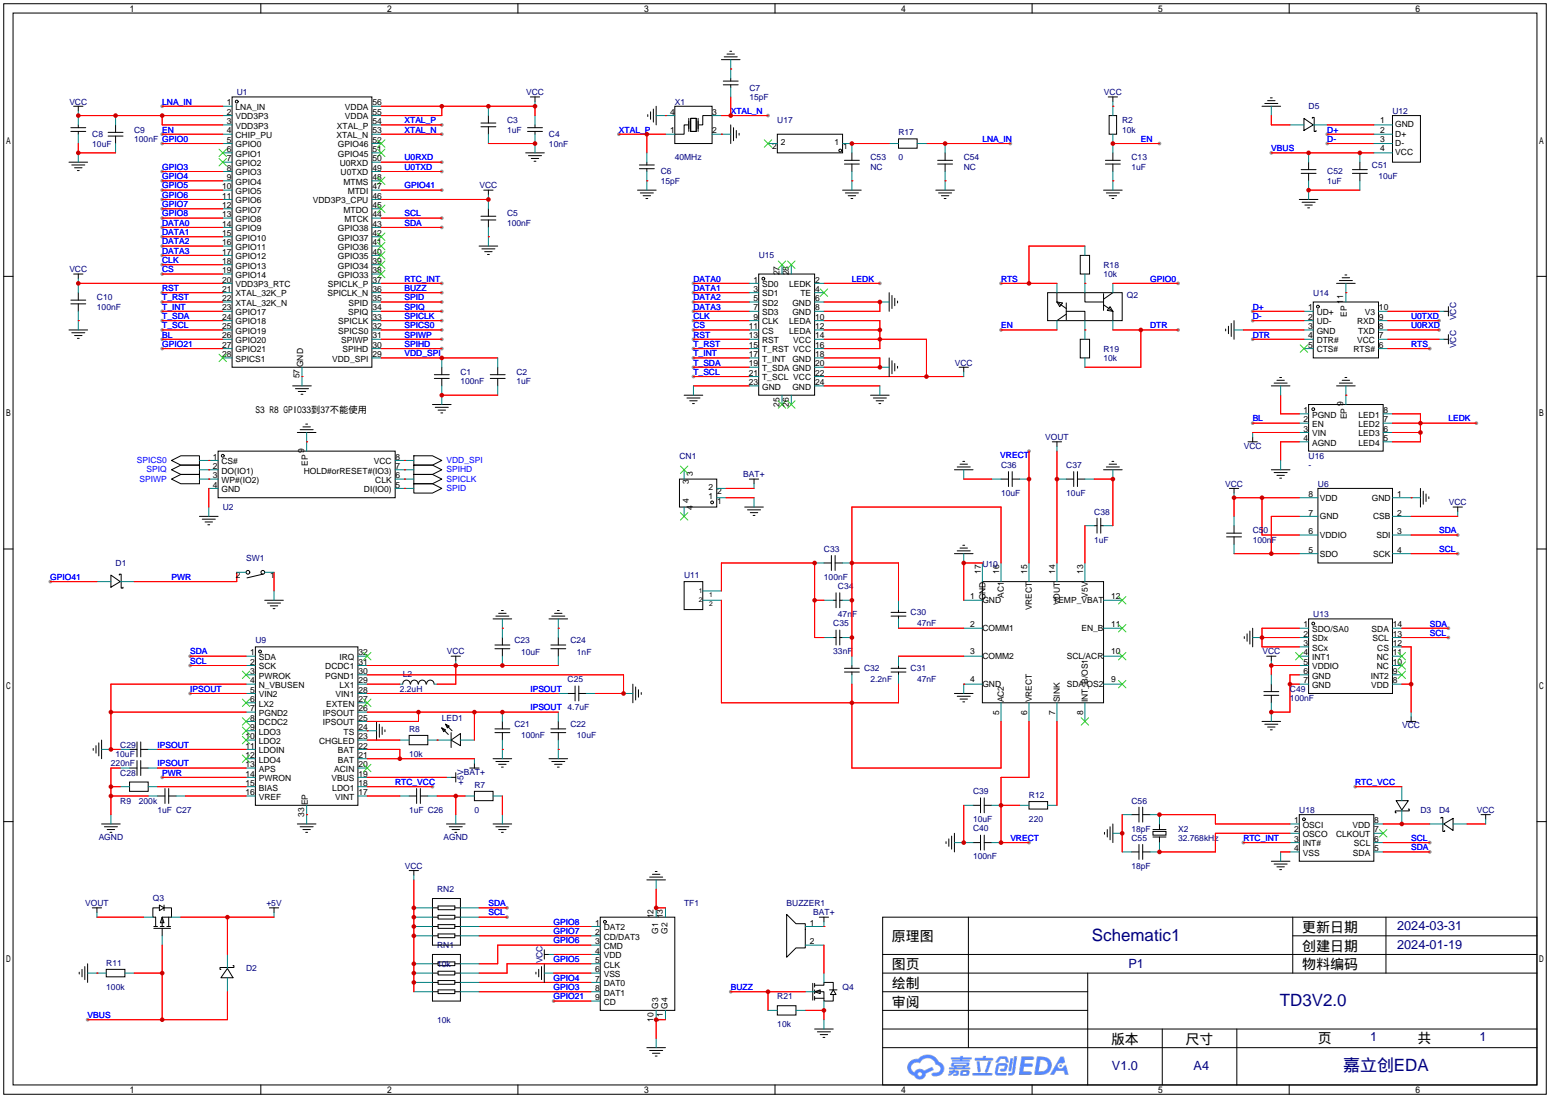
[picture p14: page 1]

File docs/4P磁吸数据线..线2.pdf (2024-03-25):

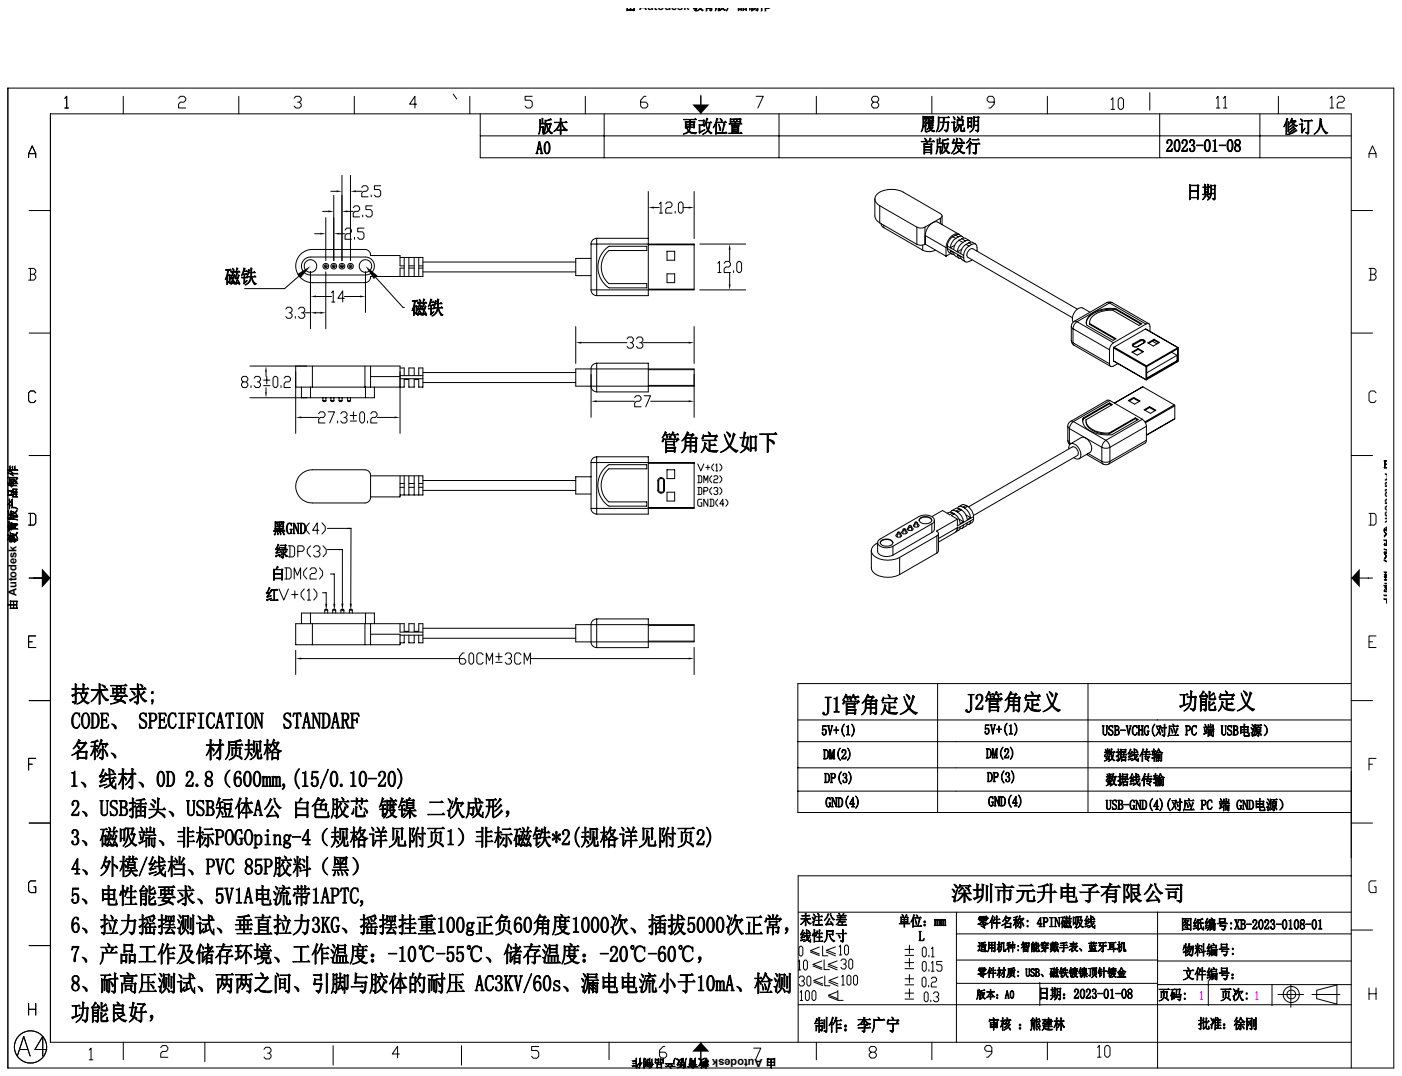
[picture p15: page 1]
由 Autodesk 教育版产品制作; 由 教育版产品制作; 深圳市元升电子有限公司

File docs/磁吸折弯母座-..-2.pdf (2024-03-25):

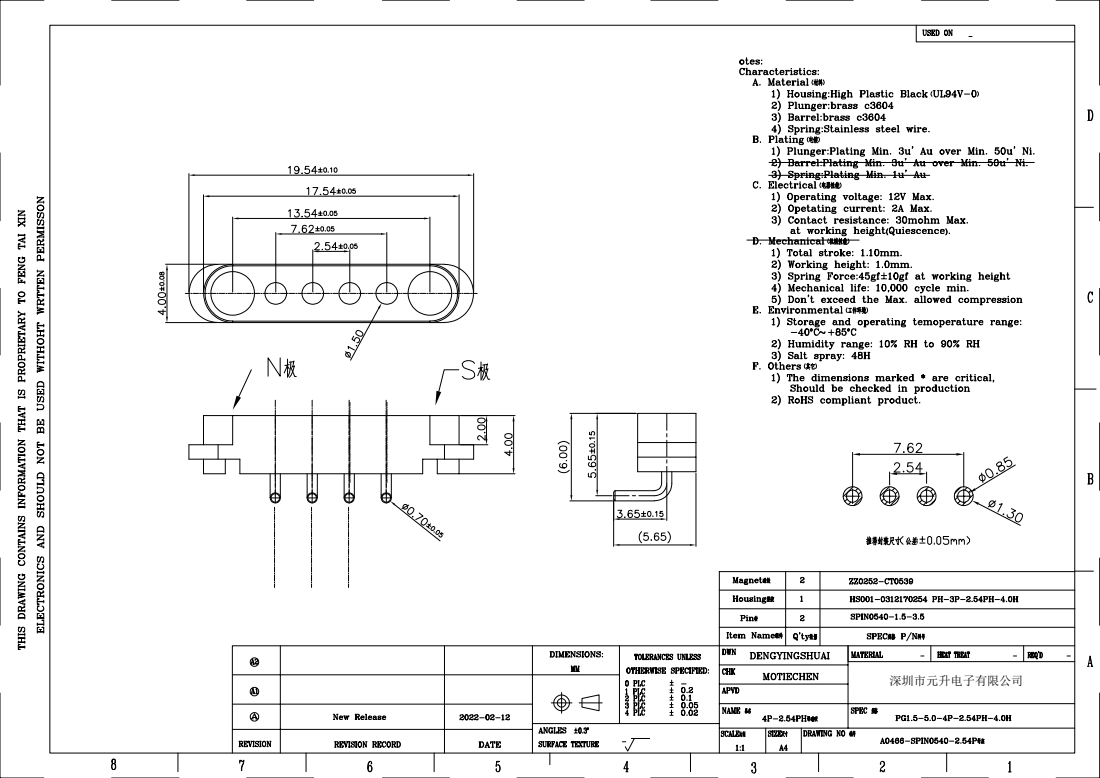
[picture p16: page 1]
深圳市元升电子有限公司

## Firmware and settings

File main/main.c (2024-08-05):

#include "HAL.h"
#include "Model.h"

static const char *TAG = "main";




void app_main()
{
  // Pre_HAL_Init();
  HAL_init();
  lvgl_task_init();
  
  Model_init();
  load_config2ram();
  // http_native_request();
  // http_process();
  // get_sram_size();
  // get_config_item_char("version");
  // update_config_item_char("version", "2.0.0");
  // load_config2ram();
  // get_config_item_char("version");

  // get_config_item_int("size");
  // update_config_item_int("size", 20);
  // load_config2ram();
  // get_config_item_int("size");
  
  // get_config_item_bool("isBool");
  // update_config_item_bool("isBool", false);
  // load_config2ram();
  // get_config_item_bool("isBool");

  // init_tone();
  
  while (1)
  {
    // if(is_sd_present()){
    //   printf("sd card is present\n");
    // } else {
    //   printf("sd card is not present\n");

    // }
    // get_sram_size();
    Page_Update();
    vTaskDelay(1000 / portTICK_PERIOD_MS);
  }
}

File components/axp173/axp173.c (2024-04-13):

/*
 * @Date: 2024-02-01 15:45:05
 * @LastEditors: AaronChu
 * @LastEditTime: 2024-04-13 13:43:42
 */
/*
 * @Date: 2024-01-31 16:12:07
 * @LastEditors: AaronChu
 * @LastEditTime: 2024-02-01 15:43:34
 */
#include "axp173.h"

static const char *TAG = "AXP173";

static float charger_level = 0.0;
static float discharge_level = 100.0;

static float max_bat_capacity = 300.0;

inline uint16_t _getMin(uint16_t a, uint16_t b)
{
  return ((a) < (b) ? (a) : (b));
}

inline uint16_t _getMax(uint16_t a, uint16_t b)
{
  return ((a) > (b) ? (a) : (b));
}


uint16_t _getMid(uint16_t input, uint16_t min, uint16_t max)
{
  return _getMax(_getMin(input, max), min);
}


inline float _getMinFloat(float a, float b)
{
  return ((a) < (b) ? (a) : (b));
}

inline float _getMaxFloat(float a, float b)
{
  return ((a) > (b) ? (a) : (b));
}

bool isACINExist()
{
  return (i2c_read_8bit(0x34, 0x00) & 0B10000000) ? true : false;
}

bool isACINAvl()
{
  return (i2c_read_8bit(0x34, 0x00) & 0B01000000) ? true : false;
}

bool isVBUSExist()
{
  return (i2c_read_8bit(0x34, 0x00) & 0B00100000) ? true : false;
}

bool isVBUSAvl()
{
  return (i2c_read_8bit(0x34, 0x00) & 0B00010000) ? true : false;
}

bool getBatCurrentDir()
{
  return (i2c_read_8bit(0x34, 0x00) & 0B00000100) ? true : false;
}

bool isAXP173OverTemp()
{
  return (i2c_read_8bit(0x34, 0x01) & 0B10000000) ? true : false;
}

bool isCharging()
{
  return (i2c_read_8bit(0x34, 0x01) & 0B01000000) ? true : false;
}

bool isBatExist()
{
  return (i2c_read_8bit(0x34, 0x01) & 0B00100000) ? true : false;
}

bool isChargeCsmaller()
{
  return (i2c_read_8bit(0x34, 0x01) & 0B00000100) ? true : false;
}

/**
 * @description: 打开或者关闭输出通道(测试通过)
 * @param {enum OUTPUT_CHANNEL} channel 输出通道
 * @param {bool} state 状态：true:打开 false: 关闭
 * @return {*}
 */
void setOutputEnable(enum OUTPUT_CHANNEL channel, bool state)
{
  uint8_t buff = i2c_read_8bit(0x34, 0x12);
  buff = state ? (buff | (1U << channel)) : (buff & ~(1U << channel));
  i2c_write_byte(0x34, 0x12, buff);
}

/**
 * @description: 设置通道的输出电压
 * @param {enum OUTPUT_CHANNEL} channel 输出通道
 * @param {uint16_t} voltage 输出电压  DCDC1 & LDO4: 700~3500(mV), DCDC2: 700~2275(mV), LDO2 & LDO3: 1800~3300{mV}
 * @return {*}
 */
void setOutputVoltage(enum OUTPUT_CHANNEL channel, uint16_t voltage)
{
  uint8_t buff = 0;
  uint16_t data[2] = {0};
  switch (channel)
  {
  case OP_DCDC1:
    voltage = (_getMid(voltage, 700, 3500) - 700) / 25;
    buff = i2c_read_8bit(0x34, 0x26);
    buff = (buff & 0B10000000) | (voltage & 0B01111111);
    i2c_write_byte(0x34, 0x26, buff);
    break;
  case OP_DCDC2:
    voltage = (_getMid(voltage, 700, 2275) - 700) / 25;
    buff = i2c_read_8bit(0x34, 0x23);
    buff = (buff & 0B11000000) | (voltage & 0B00111111);
    i2c_write_byte(0x34, 0x23, buff);
    break;
  case OP_LDO2:
    voltage = (_getMid(voltage, 1800, 3300) - 1800) / 100;
    buff = i2c_read_8bit(0x34, 0x28);
    buff = (buff & 0B00001111) | (voltage << 4);
    i2c_write_byte(0x34, 0x28, buff);
    break;
  case OP_LDO3:
    voltage = (_getMid(voltage, 1800, 3300) - 1800) / 100;
    buff = i2c_read_8bit(0x34, 0x28);
    buff = (buff & 0B11110000) | (voltage);
    i2c_write_byte(0x34, 0x28, buff);
    break;
  case OP_LDO4:
    voltage = (_getMid(voltage, 700, 3500) - 700) / 25;
    buff = i2c_read_8bit(0x34, 0x27);
    buff = (buff & 0B10000000) | (voltage & 0B01111111);
    i2c_write_byte(0x34, 0x27, buff);
    break;
  default:
    break;
  }
}

void powerOFF()
{
  i2c_write_byte(0x34, 0x32, (i2c_read_8bit(0x34, 0x32) | 0B10000000));
}

void setChargeEnable(bool state)
{
  if (state)
    i2c_write_byte(0x34, 0x33, ((i2c_read_8bit(0x34, 0x33) | 0B10000000)));
  else
    i2c_write_byte(0x34, 0x33, ((i2c_read_8bit(0x34, 0x33) & 0B01111111)));
}

void setChargeCurrent(enum CHARGE_CURRENT current)
{
  i2c_write_byte(0x34, 0x33, ((i2c_read_8bit(0x34, 0x33) & 0B11110000) | current));
}


void setADCEnable(enum ADC_CHANNEL channel, bool state)
{
  uint8_t buff = i2c_read_8bit(0x34, 0x82);
  buff = state ? (buff | (1U << channel)) : (buff & ~(1U << channel));
  i2c_write_byte(0x34, 0x82, buff);
}

void setCoulometer(enum COULOMETER_CTRL option, bool state)
{
  uint8_t buff = i2c_read_8bit(0x34, 0xB8);
  buff = state ? (buff | (1U << option)) : (buff & ~(1U << option));
  i2c_write_byte(0x34, 0xB8, buff);
}

 uint32_t getCoulometerChargeData()
{
  return i2c_read_32bit(0x34, 0xB0);
}

 uint32_t getCoulometerDischargeData()
{
  return i2c_read_32bit(0x34, 0xB4);
}

float getCoulometerData()
{
  uint32_t coin = getCoulometerChargeData();
  uint32_t coout = getCoulometerDischargeData();
  // data = 65536 * current_LSB * (coin - coout) / 3600 / ADC rate
  return 65536 * 0.5 * (int32_t)(coin - coout) / 3600.0 / 25.0;
}

float getBatVoltage()
{
  float ADCLSB = 1.1 / 1000.0;
  return i2c_read_12bit(0x34, 0x78) * ADCLSB;
}

float getBatCurrent()
{
  float ADCLSB = 0.5;
  uint16_t CurrentIn = i2c_read_13bit(0x34, 0x7A);
  uint16_t CurrentOut = i2c_read_13bit(0x34, 0x7C);
  return (CurrentIn - CurrentOut) * ADCLSB;
}

float getBatLevel()
{
  const float batVoltage = getBatVoltage();
  const float batPercentage = (batVoltage < 3.248088) ? (0) : (batVoltage - 3.120712) * 100;
  // 防止电量上下跳变
  float percentage = (batPercentage <= 100.00) ? batPercentage : 100.00;
  if(isCharging()){
    charger_level = _getMaxFloat(percentage, charger_level);
    percentage = charger_level;
  } else {
    discharge_level = _getMinFloat(percentage, discharge_level);
    percentage = discharge_level;
  }
  return percentage;
}

/**
 * @description: 利用库仑计计算剩余电量（实际并不准却，需要校准库仑计，还需要再最低电量重置库仑计）
 * @return {*}
 */
float getBatLevelWithColumeter()
{
  const float columeter = getCoulometerData();
  float real_columeter = _getMinFloat(max_bat_capacity, columeter);
  return real_columeter / max_bat_capacity * 100;
}

float getBatPower()
{
  float VoltageLSB = 1.1;
  float CurrentLCS = 0.5;
  uint32_t ReData = i2c_read_24bit(0x34, 0x70);
  return VoltageLSB * CurrentLCS * ReData / 1000.0;
}

float getVBUSVoltage()
{
  float ADCLSB = 1.7 / 1000.0;
  uint16_t ReData = i2c_read_12bit(0x34, 0x5A);
  return ReData * ADCLSB;
}

float getVBUSCurrent()
{
  float ADCLSB = 0.375;
  uint16_t ReData = i2c_read_12bit(0x34, 0x5C);
  return ReData * ADCLSB;
}

float getAXP173Temp()
{
  float ADCLSB = 0.1;
  const float OFFSET_DEG_C = -144.7;
  uint16_t ReData = i2c_read_12bit(0x34, 0x5E);
  return OFFSET_DEG_C + ReData * ADCLSB;
}

float getTSTemp()
{
  float ADCLSB = 0.1;
  const float OFFSET_DEG_C = -144.7;
  uint16_t ReData = i2c_read_12bit(0x34, 0x62);
  return OFFSET_DEG_C + ReData * ADCLSB;
}
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

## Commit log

2024-03-25 feat: v1.0
    [NU1680 Rx_EVM_PCB_Ver.1.PcbDoc, NU1680 Rx_EVM_SCH_Ver.2.SchDoc, NU1680_EVM_BOMLIST_Ver.1.xls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]
2024-03-26 feat: 天空之城MIDI音乐
2024-03-30 feat: aw9364背光驱动，pcf8563驱动
    [partitions.csv]
2024-03-30 fix: 调用蜂鸣初始化，更改充电电流
2024-04-01 feat: UI更新，同步网络对时
    [partitions.csv]
2024-04-02 fix: 移除.vscode 配置
2024-04-02 fix: 提升编译等级内联inline会报错，修改分区表
    [partitions.csv]
2024-04-02 fix: 硬件抽象层
2024-04-02 fix: 移除不需要的文件
2024-04-02 doc: 文档更新
2024-04-02 doc: 更新文档
2024-04-03 fix: 内存申请，lvgl任务堆栈大小
2024-04-03 feat: 临时模板
2024-04-03 fix: 修改menuconfig
2024-04-03 fix: 整屏缓冲
2024-04-03 doc: 更新项目层级说明
2024-04-03 feat: MVC三层结构
2024-04-03 feat: cmake添加三层结构
2024-04-03 feat: 添加文件夹遍历测试
2024-04-03 feat: 添加按钮组件，添加低功耗电源管理
2024-04-03 fix: 更新menuconfig配置
2024-04-03 fix: 分开初始化lcd跟lvgl
2024-04-03 fix: 移除入口文件中操作数据
2024-04-03 fix: 迁移所有硬件初始化函数至硬件抽象层
2024-04-03 fix: 去除重复引用
2024-04-03 feat: 解决按钮的问题，粗略控制背光
2024-04-05 feat: 添加外部库rlottie
2024-04-05 feat: 新增页面管理框架
2024-04-06 doc: 更新添加rlottie的方式
2024-04-06 fix: 同步menuconfig
2024-04-06 fix: 移除无用输出
2024-04-07 doc: 更新烧录方式指引
2024-04-07 fix: 移除页面切换动画，降低页面切换对帧率的影响
2024-04-07 feat: 添加屏幕旋转，屏幕刷新，旋转270度有错乱
2024-04-07 feat: 集成消息框架测试，迁移状态栏，修改目录结构
2024-04-08 feat: 调通时钟芯片pcf8563
2024-04-08 feat: 时钟消息同步
2024-04-09 fix: 移除无意义输出
2024-04-09 fix: 去除i2c设备初始化前的延时
2024-04-09 fix: 去除controller层，实际为mvvm的结构
2024-04-09 feat: 消息队列通知，以及viewModel功能
2024-04-09 feat: 电量数据读取
2024-04-10 feat: 状态栏更新，加大充电电流
2024-04-11 fix: 解决电压上下跳变的问题
2024-04-11 feat: 更新通过库仑计获取电量方法，需要没电后重置库仑计
2024-04-11 fix: 移除重复定义
2024-04-11 fix: 改回背光控制
2024-04-11 feat: 电量指示和充电图标动画
2024-04-11 fix: 优化充电动画的创建和删除
2024-04-13 feat: 测试背景图，界面优化
2024-04-18 feat: 调整蜂鸣器，提高qspi接口频率到40Mhz
2024-04-19 feat: 激活码激活功能测试
2024-04-20 fix: 仅定义一次定时器，防止死机
2024-04-20 fix: 移除定时器
2024-04-26 feat: 启用内部flash添加验证页面和开机页，优化页面切换事件防止溢出重启
    [partitions.csv]
2024-04-27 feat: 添加串口收发与内部内存获取
2024-05-13 feat: 串口任务间隔降低，首页添加图片
2024-05-16 feat: 结构体面板
2024-05-19 feat: 首页动态列表修改优化
2024-05-27 fix: 硬件
    [BOM_主板_Schematic1_2024-05-27.xlsx]
2024-05-27 feat: sd内容
2024-05-27 fix: BOM购买链接以及备注
    [BOM_主板_Schematic1_2024-05-27.xlsx]
2024-05-29 fix: 竖向循环切换菜单
2024-05-29 feat: 调整创建任务lvgl时机,将后续硬件交互任务都放入viewmodel层中
2024-05-29 feat: 首页切换标题
2024-05-30 feat: 更换首页图标
2024-05-30 feat: 首页标题字体
2024-05-30 feat: 添加时钟页面,解决页面清理内容溢出问题
2024-05-31 fix: 解决页面切换内存溢出的问题(第n次)
2024-05-31 fix: 去除打印响应消息
2024-05-31 非页面内操作lvgl的api加锁
2024-05-31 feat: 指针时钟界面
2024-05-31 fix: 时间换算
2024-05-31 feat: 时间角度换算
2024-05-31 feat: 时钟界面，获取RTC芯片时间
2024-06-03 doc: 添加视频地址
2024-06-03 fix: 修改首页动效，降低帧率影响，首页帧率维持在60上下
2024-06-03 feat: 添加内部字体钉钉进步体
2024-06-03 feat: 气压页面
2024-06-04 fix: 移除重复定义警告
2024-06-04 feat: 添加页面与初始化注册页面
2024-06-04 feat: 迁移cJSON,更改启动顺序
2024-06-04 feat: 添加flash内json配置文件的读写能力
2024-06-04 feat: 页面跳转
2024-06-04 fix: 去除不必要的调用，列表页记住选项位置
2024-06-06 feat: 低功耗蓝牙GATT服务
2024-06-06 fix: 暂时去除蓝牙的编译
2024-06-06 feat: 电池信息静态页面
2024-06-06 feat: 同步电池信息页面数据，修改主页应用列表左右排布
2024-06-13 feat: 陀螺仪静态图表
2024-06-13 feat: 实时陀螺仪数据
2024-06-17 fix: 陀螺仪正确的角度数据
2024-07-03 feat: 外壳按钮3D文件
    [外壳.step, 按钮.step]
2024-07-11 fix: 背光控制bug
2024-07-11 fix: 0关闭背光
2024-07-16 fix: 解决背光问题
2024-07-22 feat: 心知天气API对接测试
2024-07-22 fix: menuconfig更新
2024-08-05 feat: 添加更多页面和串口数据查看
2024-08-08 feat: 蓝牙GATT服务
2024-08-08 feat: 更新蓝牙
2024-08-08 fix: 修改蓝牙示例
2024-08-09 fix: 修改自定义蓝牙连接方式
2024-08-14 docs: 更新硬件复刻问题指导
2024-08-14 feat: 添加开源许可证
